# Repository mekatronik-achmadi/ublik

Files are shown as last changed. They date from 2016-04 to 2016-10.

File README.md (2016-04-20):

# ublik

Hello everybody out there

I’m doing a free customizable and developer-friendly mini Solar Home System (just a hobby, won’t be big and
professional like many vendors nowadays) 

I’d like any feedback on things people who understand how Solar Home System supposed to be

I call this project as Ublik. This name come from traditional oil lamp used in my country before modern electric lamp replaced it

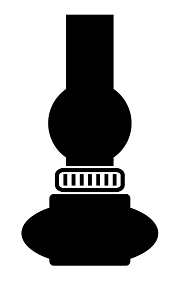
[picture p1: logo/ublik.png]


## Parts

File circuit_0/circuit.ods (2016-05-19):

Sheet: Buy
No | Component | Qty | Store | Code | Unit | Price | URL
8 | D_ZENER 5v1 | 1 | BERKAT Surabaya | - | Rp500.00 | Rp500.00 | -
18 | JACK_PWR | 1 | BERKAT Surabaya | - | Rp3,000.00 | Rp3,000.00 | -
19 | IRF9540 | 1 | BERKAT Surabaya | - | Rp3,000.00 | Rp3,000.00 | -
20 | IRF540 | 2 | BERKAT Surabaya | - | Rp3,000.00 | Rp6,000.00 | -
21 | C_25v 100u | 2 | BERKAT Surabaya | - | Rp3,000.00 | Rp6,000.00 | -
22 | USB_A | 1 | BERKAT Surabaya | - | Rp3,000.00 | Rp3,000.00 | -
23 | BUTTON 4p | 1 | BERKAT Surabaya | - | Rp1,500.00 | Rp1,500.00 | -
24 | R_1p4W 100k | 4 | BERKAT Surabaya | - | Rp25.00 | Rp100.00 | -
25 | R_1p4W 470k | 4 | BERKAT Surabaya | - | Rp25.00 | Rp100.00 | -
26 | PIN_PWR | 4 | BERKAT Surabaya | - | Rp1,500.00 | Rp6,000.00 | -
27 | PIN_HEADER | 1 | BERKAT Surabaya | - | Rp4,000.00 | Rp4,000.00
10 | MIC5205 3v3 | 1 | FAMOSA Jakarta | CMP0067 | Rp9,000.00 | Rp9,000.00 | http://www.famosastudio.com/voltage-regulator-33v-smd
6 | D_SMA 1A | 6 | LAPAN Surabaya | DIO0077 | Rp500.00 | Rp3,000.00 | http://lapantech.com/Dioda-1n4007-SMD
7 | D_SMA SCHOTTKY | 3 | LAPAN Surabaya | DIO0078 | Rp500.00 | Rp1,500.00 | http://lapantech.com/Dioda-1n5819-SMD
17 | JACK_AUDIO | 1 | LAPAN Surabaya | CJT041 | Rp3,000.00 | Rp3,000.00 | http://lapantech.com/Stereo-Jack-Socket-PCB-5-Pin-3.5mm-Green
1 | STM32F100C4 | 1 | SFE Malang | ICMC020102004 | Rp30,000.00 | Rp30,000.00 | http://sfe-electronics.com/microcontroller-ic/2488-stm32f100c4t6b.html
2 | R_0805 330 | 20 | SFE Malang | R010203018 | Rp50.00 | Rp1,000.00 | http://sfe-electronics.com/resistor/619-330-ohm-smd0805-resistor.html
3 | R_0805 4k7 | 10 | SFE Malang | R010203028 | Rp50.00 | Rp500.00 | http://sfe-electronics.com/resistor/629-47k-ohm-smd0805-resistor.html
4 | R_0805 100k | 10 | SFE Malang | R010203042 | Rp50.00 | Rp500.00 | http://sfe-electronics.com/resistor/643-100k-ohm-smd0805-resistor.html
5 | C_0805 100n | 10 | SFE Malang | C010203032 | Rp75.00 | Rp750.00 | http://sfe-electronics.com/capacitor/129-100nf-smd0805-capacitor.html
9 | PC817 | 4 | SFE Malang | ICOPT01006 | Rp1,500.00 | Rp6,000.00 | http://sfe-electronics.com/optocoupler/1192-pc-817.html
11 | LM2596s 5v | 1 | SFE Malang | ICVR02016 | Rp10,000.00 | Rp10,000.00 | http://sfe-electronics.com/integrated-circuit/918-lm2596s-50-to-263.html
12 | LED_0805 Red | 4 | SFE Malang | LED0302001 | Rp500.00 | Rp2,000.00 | http://sfe-electronics.com/display/1384-smd0805-red-led.html
13 | LED_0805 Orange | 4 | SFE Malang | LED0302002 | Rp500.00 | Rp2,000.00 | http://sfe-electronics.com/display/1385-smd0805-yellow-led.html
14 | LED_0805 Yellow | 4 | SFE Malang | LED0302004 | Rp500.00 | Rp2,000.00 | http://sfe-electronics.com/display/3066-smd0805-yellow-green-led.html
15 | LED_0805 Green | 4 | SFE Malang | LED0302003 | Rp500.00 | Rp2,000.00 | http://sfe-electronics.com/display/1386-smd0805-green-led.html
16 | IND_PWR 33mH | 1 | SFE Malang | L0103004 | Rp2,000.00 | Rp2,000.00 | http://sfe-electronics.com/inductor/2497-33uh-power-inductor.html
 | Store |  | Total
 | SFE Malang | = | Rp58,750.00
 | BERKAT Surabaya | = | Rp14,700.00
 | LAPAN Surabaya | = | Rp4,000.00
 | FAMOSA Jakarta | = | Rp9,000.00

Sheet: circuit
Id | Designator | Package | Quantity | Designation | Supplier and ref
1 | STM32 | TQFP-48_7x7mm_Pitch0.5mm | 1 | STM32F100C4
2 | R-L-USB1,R-L-PV1,R-L4,R-L3,R-L2,R-L1,R-L-LAMP1,R-PV3,R-LAMP1,R-USB1,R-L-IND1 | R_0805_HandSoldering | 11 | 330
3 | J1 | JACK_LAPAN | 1 | audio-jack
4 | PIN3,P-BOOT1,SW-PWR1,P-VDD-3V3,P-GND1,P-VDD1 | Pin_Header_Straight_1x02 | 6 | CONN_01X02
5 | SW-NRST1 | B3F-10XX | 1 | 10-XX_B3F-10XX
6 | P-COMM1,PIN4 | Pin_Header_Straight_1x04 | 2 | CONN_01X04
7 | BATT1,BATT2,BATT3,BATT4 | SparkFun-1X02_XTRA_BIG | 4 | M02PTH
8 | R-ADC-BATT1 | Resistor_Horizontal_RM10mm | 1 | 470k
9 | R-ADC-BATT2 | Resistor_Horizontal_RM10mm | 1 | 100k
10 | L-LAMP1,L-USB1,L1,L2,L3,L4,L-PV1,L-IND1 | LED-0805 | 8 | LED
11 | C-ADC1 | C_0805_HandSoldering | 3 | 100n
12 | R-NRST1,R-PV1,R-PV4,R-LAMP2,R-USB2 | R_0805_HandSoldering | 5 | 4k7
13 | CON-PV1 | JACK_ALIM | 1 | BARREL_JACK
14 | OK-PV1,OK-PV2,OK-LAMP1,OK-USB1 | DIP-4_W7.62mm | 4 | PC817
15 | R-PV2 | R_0805_HandSoldering | 1 | 100k
16 | TR-PV1 | TO220BV | 1 | IRF9530_TO220BV
17 | D-PV1,D-LAMP1,D-USB1,D-VDD1,D-3V3,D-LAMP2 | SMA_Handsoldering | 6 | D
18 | TR-LAMP1,TR-USB1 | TO220BV | 2 | IRF530_TO220BV
19 | U1 | SOT-23-5 | 1 | MIC5219BM5_SOT23-5
20 | C_VUSB1,C_VUSB2 | C_Radial_D5_L6_P2.5 | 2 | 100u
21 | D-VUSB1,D-VUSB2,D-LAMP3 | SMA_Handsoldering | 3 | D_Schottky
22 | D1 | MELF_Handsoldering | 1 | 5v1
23 | IC-VUSB1 | TO-263-5Lead | 1 | LM2596S
24 | L-VUSB1 | INDUCTOR_V | 1 | INDUCTOR
25 | P1 | USB_A | 1 | USB_A
26 | PIN1 | Pin_Header_Straight_1x03 | 1 | CONN_01X03
27 | PIN2 | Pin_Header_Straight_1x08 | 1 | CONN_01X08
28 | W1,W2,W3,W4,W5,W6,W7,W8,W9,W10,W11,W12,W13,W14 | test-pad | 14 | TEST_1P
29 | G*** | LOGO | 1 | UBLIK

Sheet: SFE
No | Component | Qty | Code
1 | STM32F100C4 | 2 | ICMC020102004
2 | R_0805 330 | 20 | R010203018
3 | R_0805 4k7 | 10 | R010203028
4 | R_0805 100k | 10 | R010203042
5 | C_0805 100n | 10 | C010203032
6 | PC817 | 4 | ICOPT01006
7 | LM2596s 5v | 2 | ICVR02016
8 | LED_0805 Red | 4 | LED0302001
9 | LED_0805 Orange | 4 | LED0302002
10 | LED_0805 Yellow | 4 | LED0302004
11 | LED_0805 Green | 4 | LED0302003
12 | IND_PWR 33mH | 2 | L0103004

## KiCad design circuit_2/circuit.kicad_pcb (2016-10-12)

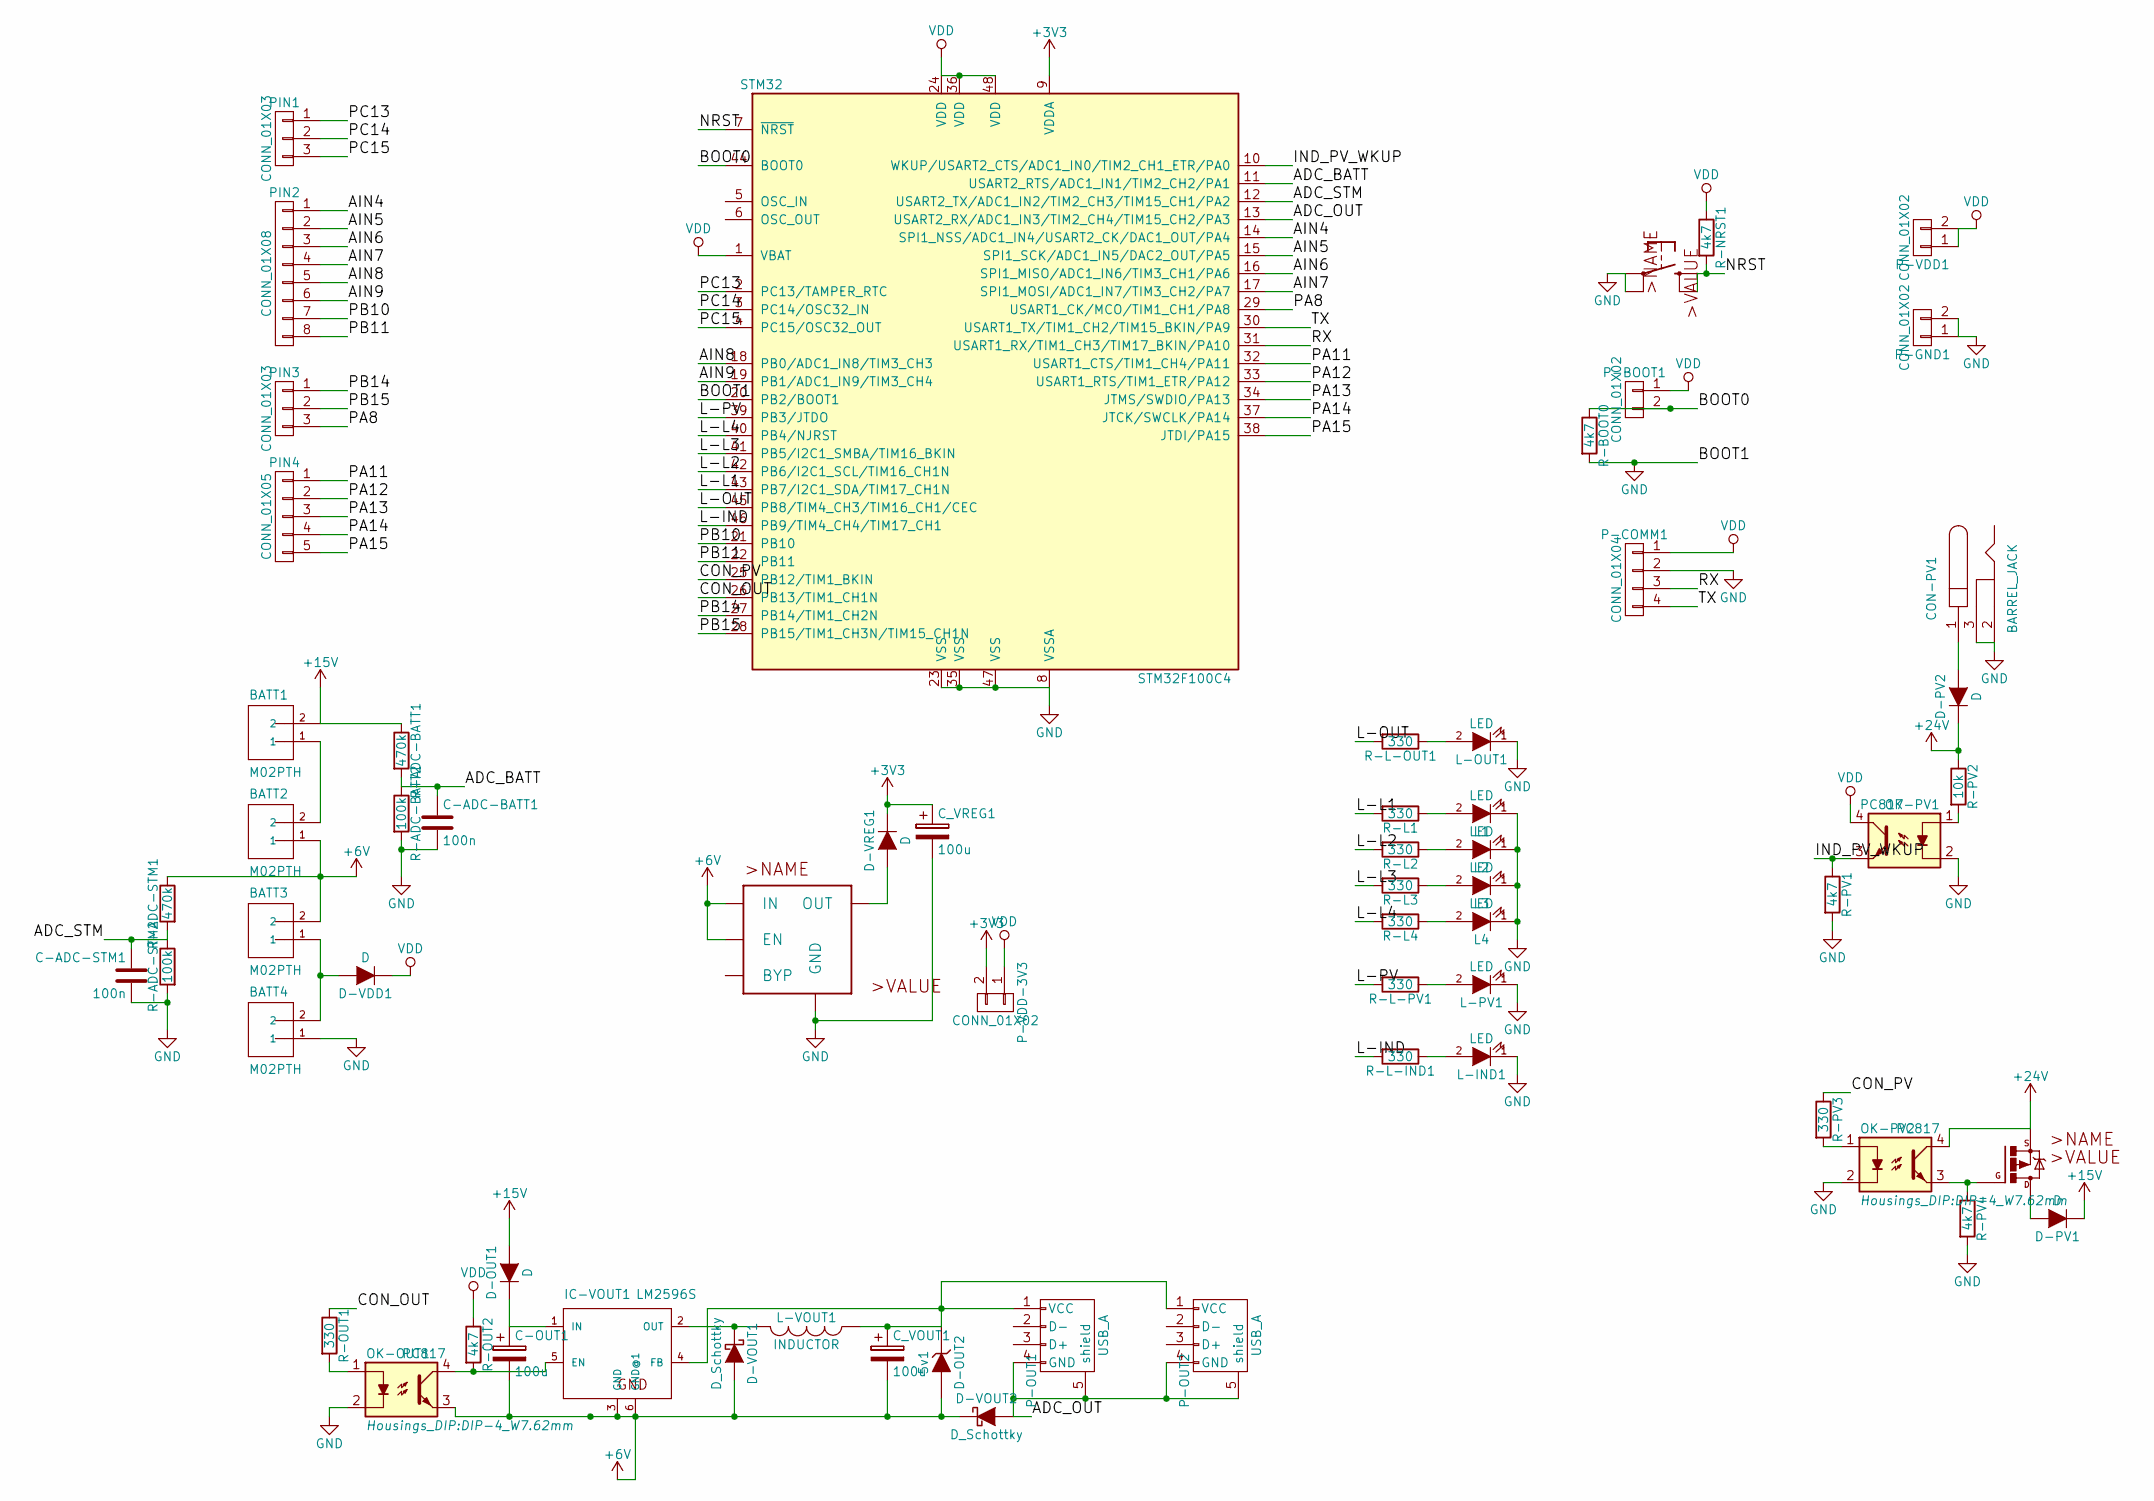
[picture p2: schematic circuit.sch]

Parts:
BATT1, BATT2, BATT3, BATT4: M02PTH; SparkFun-1X02_XTRA_BIG
C-ADC-BATT1: 100n; C_0805_HandSoldering
C-ADC-STM1: 100n; C_0805_HandSoldering
C-OUT1: 100u; C_Radial_D5_L6_P2.5
CON-PV1: BARREL_JACK; JACK_ALIM
C_VOUT1: 100u; C_Radial_D5_L6_P2.5
C_VREG1: 100u; C_Radial_D5_L6_P2.5
D-OUT1: D; SMA_Handsoldering
D-OUT2: 5v1; MELF_Handsoldering
D-PV1, D-PV2: D; SMA_Handsoldering
D-VDD1: D; SMA_Handsoldering
D-VOUT1, D-VOUT2: D_Schottky; SMA_Handsoldering
D-VREG1: D; SMA_Handsoldering
IC-VOUT1: LM2596S; TO-263-5Lead
L1, L2, L3, L4: LED; LED-0805
L-IND1: LED; LED-0805
L-OUT1: LED; LED-0805
L-PV1: LED; LED-0805
L-VOUT1: INDUCTOR; INDUCTOR_V
OK-OUT1: PC817; DIP-4_W7.62mm
OK-PV1, OK-PV2: PC817; DIP-4_W7.62mm
P-BOOT1: CONN_01X02; Pin_Header_Straight_1x02
P-COMM1: CONN_01X04; Pin_Header_Straight_1x04
P-GND1: CONN_01X02; Pin_Header_Straight_1x02
P-OUT1, P-OUT2: USB_A
P-VDD1: CONN_01X02; Pin_Header_Straight_1x02
P-VDD-3V3: CONN_01X02; Pin_Header_Straight_1x02
PIN1, PIN3: CONN_01X03; Pin_Header_Straight_1x03
PIN2: CONN_01X08; Pin_Header_Straight_1x08
PIN4: CONN_01X05; Pin_Header_Straight_1x05
R-ADC-BATT1: 470k; R_0805_HandSoldering
R-ADC-BATT2: 100k; R_0805_HandSoldering
R-ADC-STM1: 470k; R_0805_HandSoldering
R-ADC-STM2: 100k; R_0805_HandSoldering
R-BOOT0: 4k7; R_0805_HandSoldering
R-L1, R-L2, R-L3, R-L4: 330; R_0805_HandSoldering
R-L-IND1: 330; R_0805_HandSoldering
R-L-OUT1: 330; R_0805_HandSoldering
R-L-PV1: 330; R_0805_HandSoldering
R-NRST1: 4k7; R_0805_HandSoldering
R-OUT1: 330; R_0805_HandSoldering
R-OUT2: 4k7; R_0805_HandSoldering
R-PV1, R-PV4: 4k7; R_0805_HandSoldering
R-PV2: 10k; R_0805_HandSoldering
R-PV3: 330; R_0805_HandSoldering
STM32: STM32F100C4; TQFP-48_7x7mm_Pitch0.5mm
SW-NRST1: 10-XX_B3F-10XX; B3F-10XX
TR-PV1: IRF9530_TO220BV; D2PACK
U1: MIC5219BM5_SOT23-5; SOT-23-5

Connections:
+3V3: C_VREG1.1, D-VREG1.1 (K), P-VDD-3V3.2, STM32.9 (VDDA)
+6V: BATT2.1, BATT3.2, C-OUT1.2, C_VOUT1.2, D-OUT2.2 (A), D-VOUT1.2 (A), D-VOUT2.1 (K), IC-VOUT1.3 (GND), IC-VOUT1.6 (GND@1), OK-OUT1.3, R-ADC-STM1.1, U1.1 (IN), U1.3 (EN)
+15V: BATT1.2, D-OUT1.2 (A), D-PV1.1 (K), R-ADC-BATT1.1
+24V: D-PV2.1 (K), OK-PV2.4, R-PV2.1, TR-PV1.S
/ADC_BATT: C-ADC-BATT1.1, R-ADC-BATT1.2, R-ADC-BATT2.1, STM32.11 (USART2_RTS/ADC1_IN1/TIM2_CH2/PA1)
/ADC_OUT: D-VOUT2.2 (A), P-OUT1.4 (GND), P-OUT1.5 (shield), P-OUT2.4 (GND), P-OUT2.5 (shield), STM32.13 (USART2_RX/ADC1_IN3/TIM2_CH4/TIM15_CH2/P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)
/ADC_STM: C-ADC-STM1.1, R-ADC-STM1.2, R-ADC-STM2.1, STM32.12 (USART2_TX/ADC1_IN2/TIM2_CH3/TIM15_CH1/P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)
/AIN4: PIN2.1, STM32.14 (SPI1_NSS/ADC1_IN4/USART2_CK/DAC1_OUT/PA4)
/AIN5: PIN2.2, STM32.15 (SPI1_SCK/ADC1_IN5/DAC2_OUT/PA5)
/AIN6: PIN2.3, STM32.16 (SPI1_MISO/ADC1_IN6/TIM3_CH1/PA6)
/AIN7: PIN2.4, STM32.17 (SPI1_MOSI/ADC1_IN7/TIM3_CH2/PA7)
/AIN8: PIN2.5, STM32.18 (PB0/ADC1_IN8/TIM3_CH3)
/AIN9: PIN2.6, STM32.19 (PB1/ADC1_IN9/TIM3_CH4)
/BOOT0: P-BOOT1.2, R-BOOT0.1, STM32.44 (BOOT0)
/CON_OUT: R-OUT1.1, STM32.26 (PB13/TIM1_CH1N)
/CON_PV: R-PV3.1, STM32.25 (PB12/TIM1_BKIN)
/IND_PV_WKUP: OK-PV1.3, R-PV1.1, STM32.10 (WKUP/USART2_CTS/ADC1_IN0/TIM2_CH1_ETR/P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)
/L-IND: R-L-IND1.2, STM32.46 (PB9/TIM4_CH4/TIM17_CH1)
/L-L1: R-L1.2, STM32.43 (PB7/I2C1_SDA/TIM17_CH1N)
/L-L2: R-L2.2, STM32.42 (PB6/I2C1_SCL/TIM16_CH1N)
/L-L3: R-L3.2, STM32.41 (PB5/I2C1_SMBA/TIM16_BKIN)
/L-L4: R-L4.2, STM32.40 (PB4/NJRST)
/L-OUT: R-L-OUT1.2, STM32.45 (PB8/TIM4_CH3/TIM16_CH1/CEC)
/L-PV: R-L-PV1.2, STM32.39 (PB3/JTDO)
/NRST: R-NRST1.2, STM32.7 (~NRST), SW-NRST1.1 (S), SW-NRST1.2 (S1)
/PA8: PIN3.3, STM32.29 (USART1_CK/MCO/TIM1_CH1/PA8)
/PA11: PIN4.1, STM32.32 (USART1_CTS/TIM1_CH4/PA11)
/PA12: PIN4.2, STM32.33 (USART1_RTS/TIM1_ETR/PA12)
/PA13: PIN4.3, STM32.34 (JTMS/SWDIO/PA13)
/PA14: PIN4.4, STM32.37 (JTCK/SWCLK/PA14)
/PA15: PIN4.5, STM32.38 (JTDI/PA15)
/PB10: PIN2.7, STM32.21 (PB10)
/PB11: PIN2.8, STM32.22 (PB11)
/PB14: PIN3.1, STM32.27 (PB14/TIM1_CH2N)
/PB15: PIN3.2, STM32.28 (PB15/TIM1_CH3N/TIM15_CH1N)
/PC13: PIN1.1, STM32.2 (PC13/TAMPER_RTC)
/PC14: PIN1.2, STM32.3 (PC14/OSC32_IN)
/PC15: PIN1.3, STM32.4 (PC15/OSC32_OUT)
/RX: P-COMM1.3, STM32.31 (USART1_RX/TIM1_CH3/TIM17_BKIN/PA10)
/TX: P-COMM1.4, STM32.30 (USART1_TX/TIM1_CH2/TIM15_BKIN/PA9)
GND: BATT4.1, C-ADC-BATT1.2, C-ADC-STM1.2, CON-PV1.2, CON-PV1.3, C_VREG1.2, L1.1 (K), L2.1 (K), L3.1 (K), L4.1 (K), L-IND1.1 (K), L-OUT1.1 (K), L-PV1.1 (K), OK-OUT1.2, OK-PV1.2, OK-PV2.2, P-COMM1.2, P-GND1.1, P-GND1.2, R-ADC-BATT2.2, R-ADC-STM2.2, R-BOOT0.2, R-PV1.2, R-PV4.2, STM32.8 (VSSA), STM32.20 (PB2/BOOT1), STM32.23 (VSS), STM32.35 (VSS), STM32.47 (VSS), SW-NRST1.3, SW-NRST1.4 (P1), U1.2 (GND)
unnamed: BATT1.1, BATT2.2
unnamed: BATT3.1, BATT4.2, D-VDD1.2 (A)
unnamed: C-OUT1.1, D-OUT1.1 (K), IC-VOUT1.1 (IN)
unnamed: CON-PV1.1, D-PV2.2 (A)
unnamed: C_VOUT1.1, D-OUT2.1 (K), IC-VOUT1.4 (FB), L-VOUT1.1, P-OUT1.1 (VCC), P-OUT2.1 (VCC)
unnamed: D-PV1.2 (A), TR-PV1.D
unnamed: D-VOUT1.1 (K), IC-VOUT1.2 (OUT), L-VOUT1.2
unnamed: D-VREG1.2 (A), U1.5 (OUT)
unnamed: IC-VOUT1.5 (EN), OK-OUT1.4, R-OUT2.2
unnamed: L1.2 (A), R-L1.1
unnamed: L2.2 (A), R-L2.1
unnamed: L3.2 (A), R-L3.1
unnamed: L4.2 (A), R-L4.1
unnamed: L-IND1.2 (A), R-L-IND1.1
unnamed: L-OUT1.2 (A), R-L-OUT1.1
unnamed: L-PV1.2 (A), R-L-PV1.1
unnamed: OK-OUT1.1, R-OUT1.2
unnamed: OK-PV1.1, R-PV2.2
unnamed: OK-PV2.1, R-PV3.2
unnamed: OK-PV2.3, R-PV4.1, TR-PV1.G
VDD: D-VDD1.1 (K), OK-PV1.4, P-BOOT1.1, P-COMM1.1, P-VDD1.1, P-VDD1.2, P-VDD-3V3.1, R-NRST1.1, R-OUT2.1, STM32.1 (VBAT), STM32.24 (VDD), STM32.36 (VDD), STM32.48 (VDD)

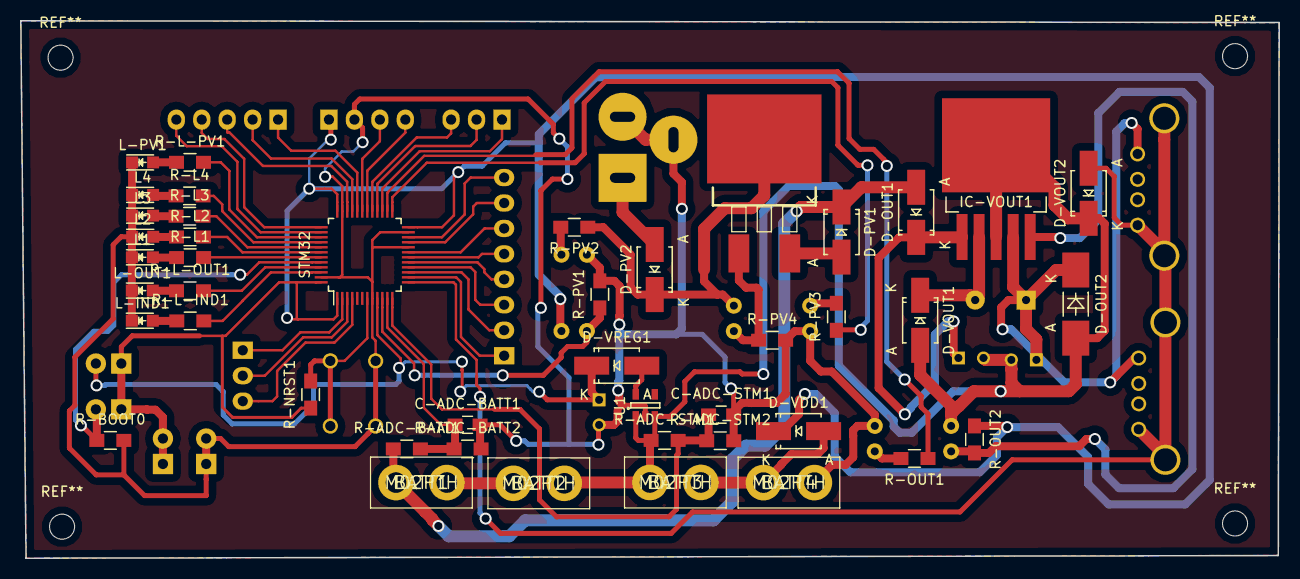
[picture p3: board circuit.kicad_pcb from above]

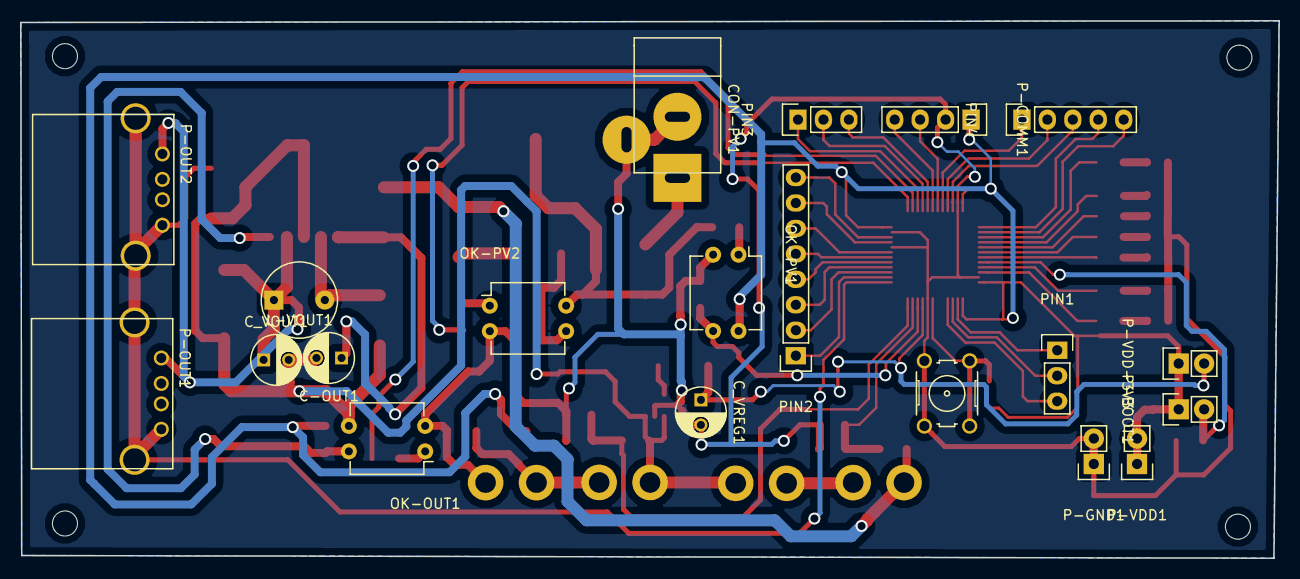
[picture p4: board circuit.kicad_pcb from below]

Board: 2 copper layers, 125.6 x 53.6 mm, 64 parts (20 on the bottom side), 62 nets.

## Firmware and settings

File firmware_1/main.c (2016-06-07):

#include "inklusi.h"

#if RUN_WORK

int main(void) {

/*
 * Initializing system
 */
  ublik_init();

/*
 * Output starting
 */
  ublik_out();

/*
 * Perform Indicating
 */
  ublik_ind();

  while (true){
/*
 * Sending some data
 */
    ublik_data();

/*
 * Battere level control
 */
    ublik_batt();

/*
 * Going Sleep
 */
    ublik_sleep();

/*
 * Waking up from Sleep
 */
    ublik_wkup();

/*
 * Continue To next Loop
 */
     delay_ms(proc_tunda);

  }

  return 0;
}

#endif

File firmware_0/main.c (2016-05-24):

#include "inklusi.h"

#if RUN_TEST

int main(void){
/*
 * Initializing system
 */
  ublik_init();


}

#endif

#if RUN_WORK

int main(void) {

/*
 * Initializing system
 */
  ublik_init();

/*
 * Perform Indicating
 */
  ublik_ind();

/*
 * Battere level control
 */
  ublik_batt();

  while (true){
/*
 * Sending some data
 */
    ublik_data();

/*
 * Going Sleep
 */
    ublik_sleep();

/*
 * Waking up from Sleep
 */
    ublik_wkup();

/*
 * Battere level control
 */
    ublik_batt();

/*
 * Continue To next Loop
 */
     delay_ms(proc_tunda);

  }

  return 0;
}

#endif

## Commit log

2016-04-28 support stm32f100c4
2016-04-29 work on circuit
    [circuit.kicad_pcb, circuit.sch]
2016-05-03 circuit building
    [circuit.kicad_pcb, circuit.sch]
2016-05-03 tambah test pad
    [circuit.kicad_pcb, circuit.sch]
2016-05-03 circuit finish
    [circuit.kicad_pcb]
2016-05-10 circuit fabricated
    [circuit.kicad_pcb]
2016-05-12 tinggal ADC Battery
2016-05-14 list components
    [circuit.kicad_pcb, circuit.ods, circuit.sch]
2016-05-19 under test
    [circuit.ods]
2016-05-24 stm32f1013 ok
    [batt-conv.ods]
2016-05-24 f100c4 added
    [batt-conv.ods, circuit.kicad_pcb]
2016-06-14 proto src
    [batt-conv.ods]
2016-06-20 new design
    [batt-conv.ods, circuit.kicad_pcb, circuit.ods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]
2016-09-20 circuit full 5v
    [circuit.kicad_pcb, circuit.sch]
2016-10-12 circuit 2
    [circuit.kicad_pcb]
